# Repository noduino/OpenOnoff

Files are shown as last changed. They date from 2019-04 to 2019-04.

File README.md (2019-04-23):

Noduino Open Onoff
=======================================

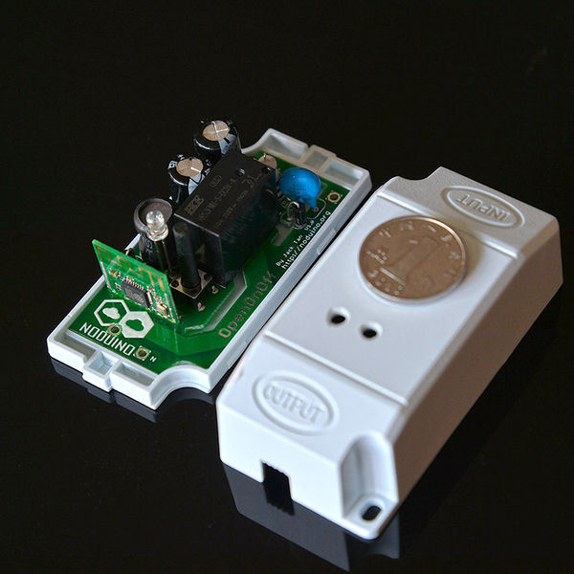
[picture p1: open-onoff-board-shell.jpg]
Noduino Open Onoff Shell


[*Noduino Open Onoff (OpenOnoff V1.0)*](http://wiki.jackslab.org/Noduino_OpenOnoff)

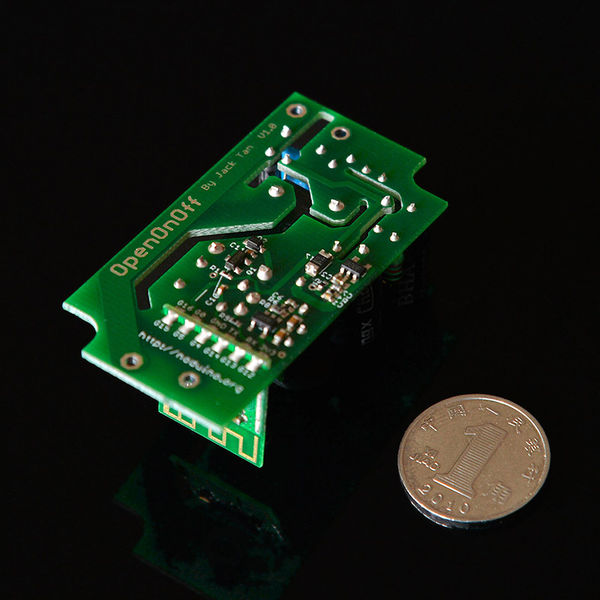
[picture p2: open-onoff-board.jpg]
Noduino Open Onoff Board


[*Noduino Open Onoff (OpenOnoff V1.0)*](http://wiki.jackslab.org/Noduino_OpenOnoff)

Overview
-------------------

* AC 85V - 250V WiFi Smart Switch
* ESP8285 inside
* 250V 10A relay
* Shell size 63mm x 33mm x 21mm (H)

Shell
-------------------

* https://item.taobao.com/item.htm?id=535597515580

WiFi Module
-------------------

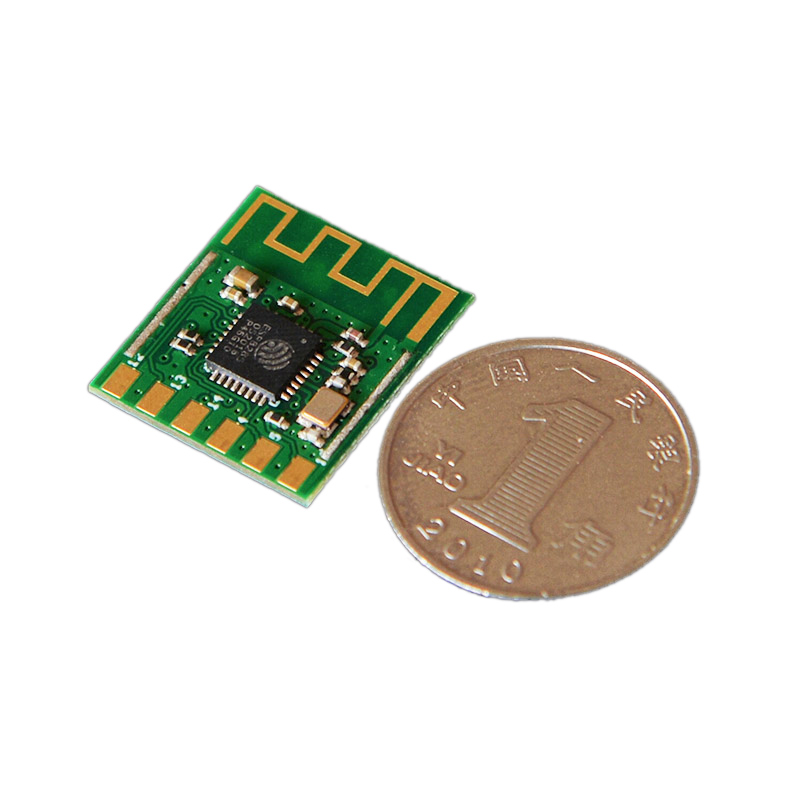
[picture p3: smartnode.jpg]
NodeC


[*Noduino NodeC WiFi Module*](http://wiki.jackslab.org/Noduino_SmartNode)

SCH
-------------------

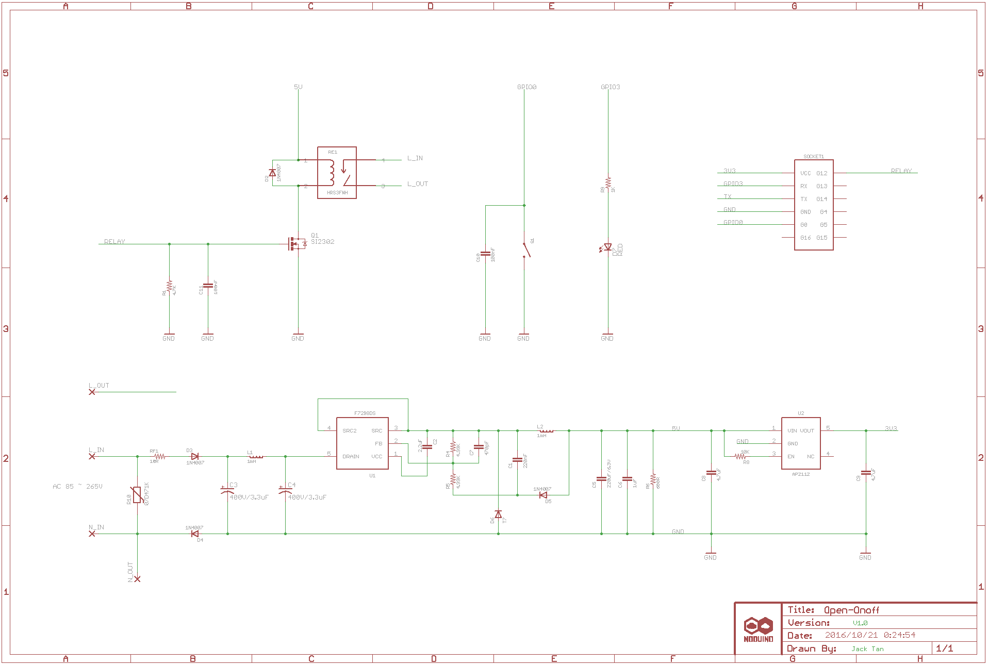
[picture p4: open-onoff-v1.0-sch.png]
Noduino Open Onoff sch


[*Noduino Open Onoff (OpenOnoff V1.0)*](http://wiki.jackslab.org/Noduino_OpenOnoff)

Layout
-------------------

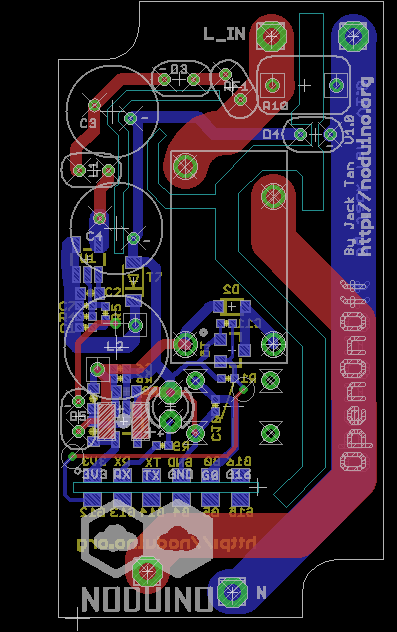
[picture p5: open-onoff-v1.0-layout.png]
Noduino Open Onoff layout


[*Noduino Open Onoff (OpenOnoff V1.0)*](http://wiki.jackslab.org/Noduino_OpenOnoff)

WiKi
-------------------

* http://wiki.jackslab.org/Noduino_OpenOnoff

License Information
-------------------
The hardware is released under [Creative Commons ShareAlike 4.0 International](https://creativecommons.org/licenses/by-sa/4.0/).

Distributed as-is; no warranty is given.

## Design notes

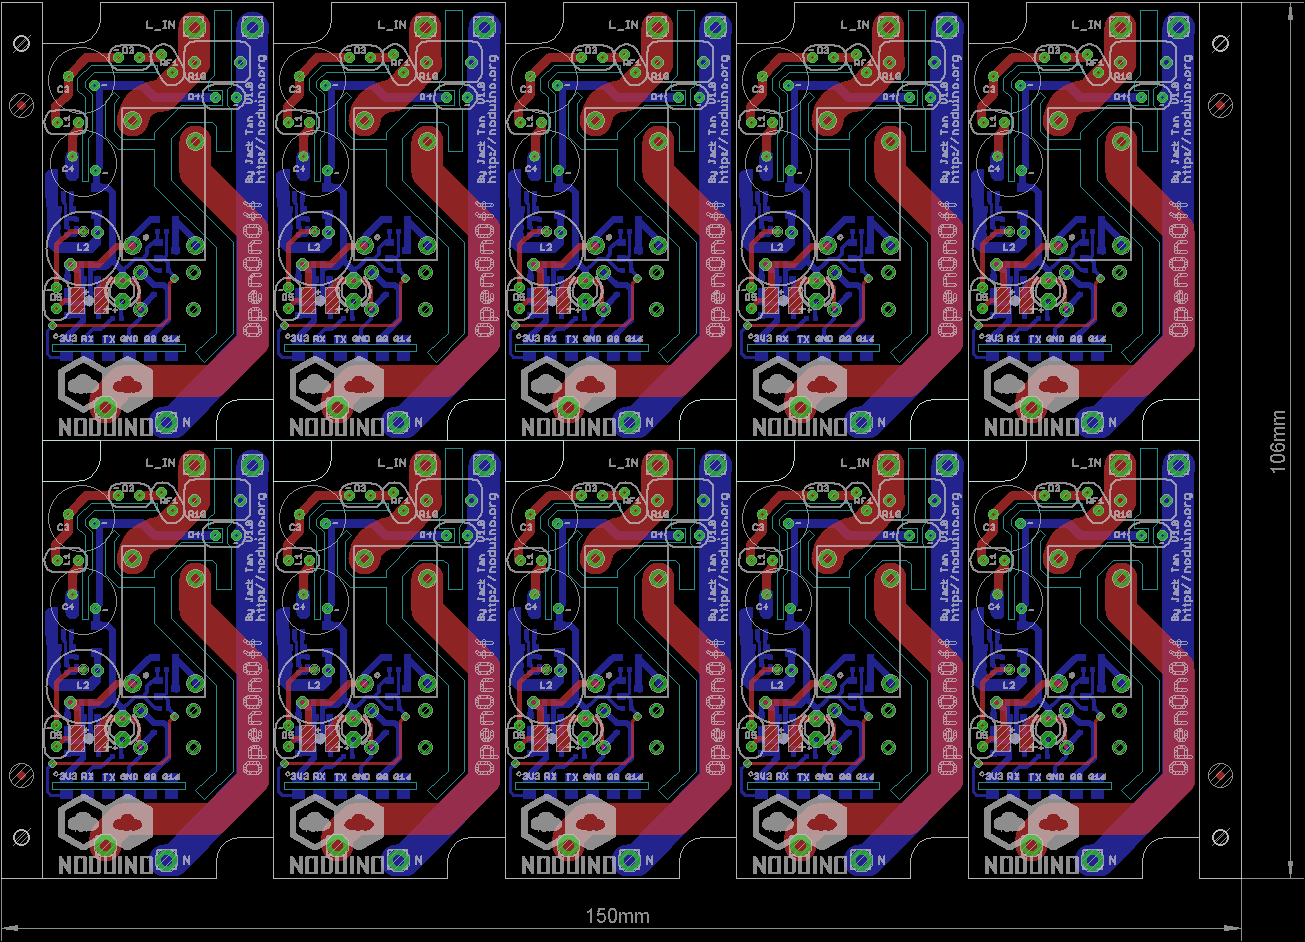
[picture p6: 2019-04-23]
V1.0/Noduino-Open-Onoff-V1.0-Produce-layout.png

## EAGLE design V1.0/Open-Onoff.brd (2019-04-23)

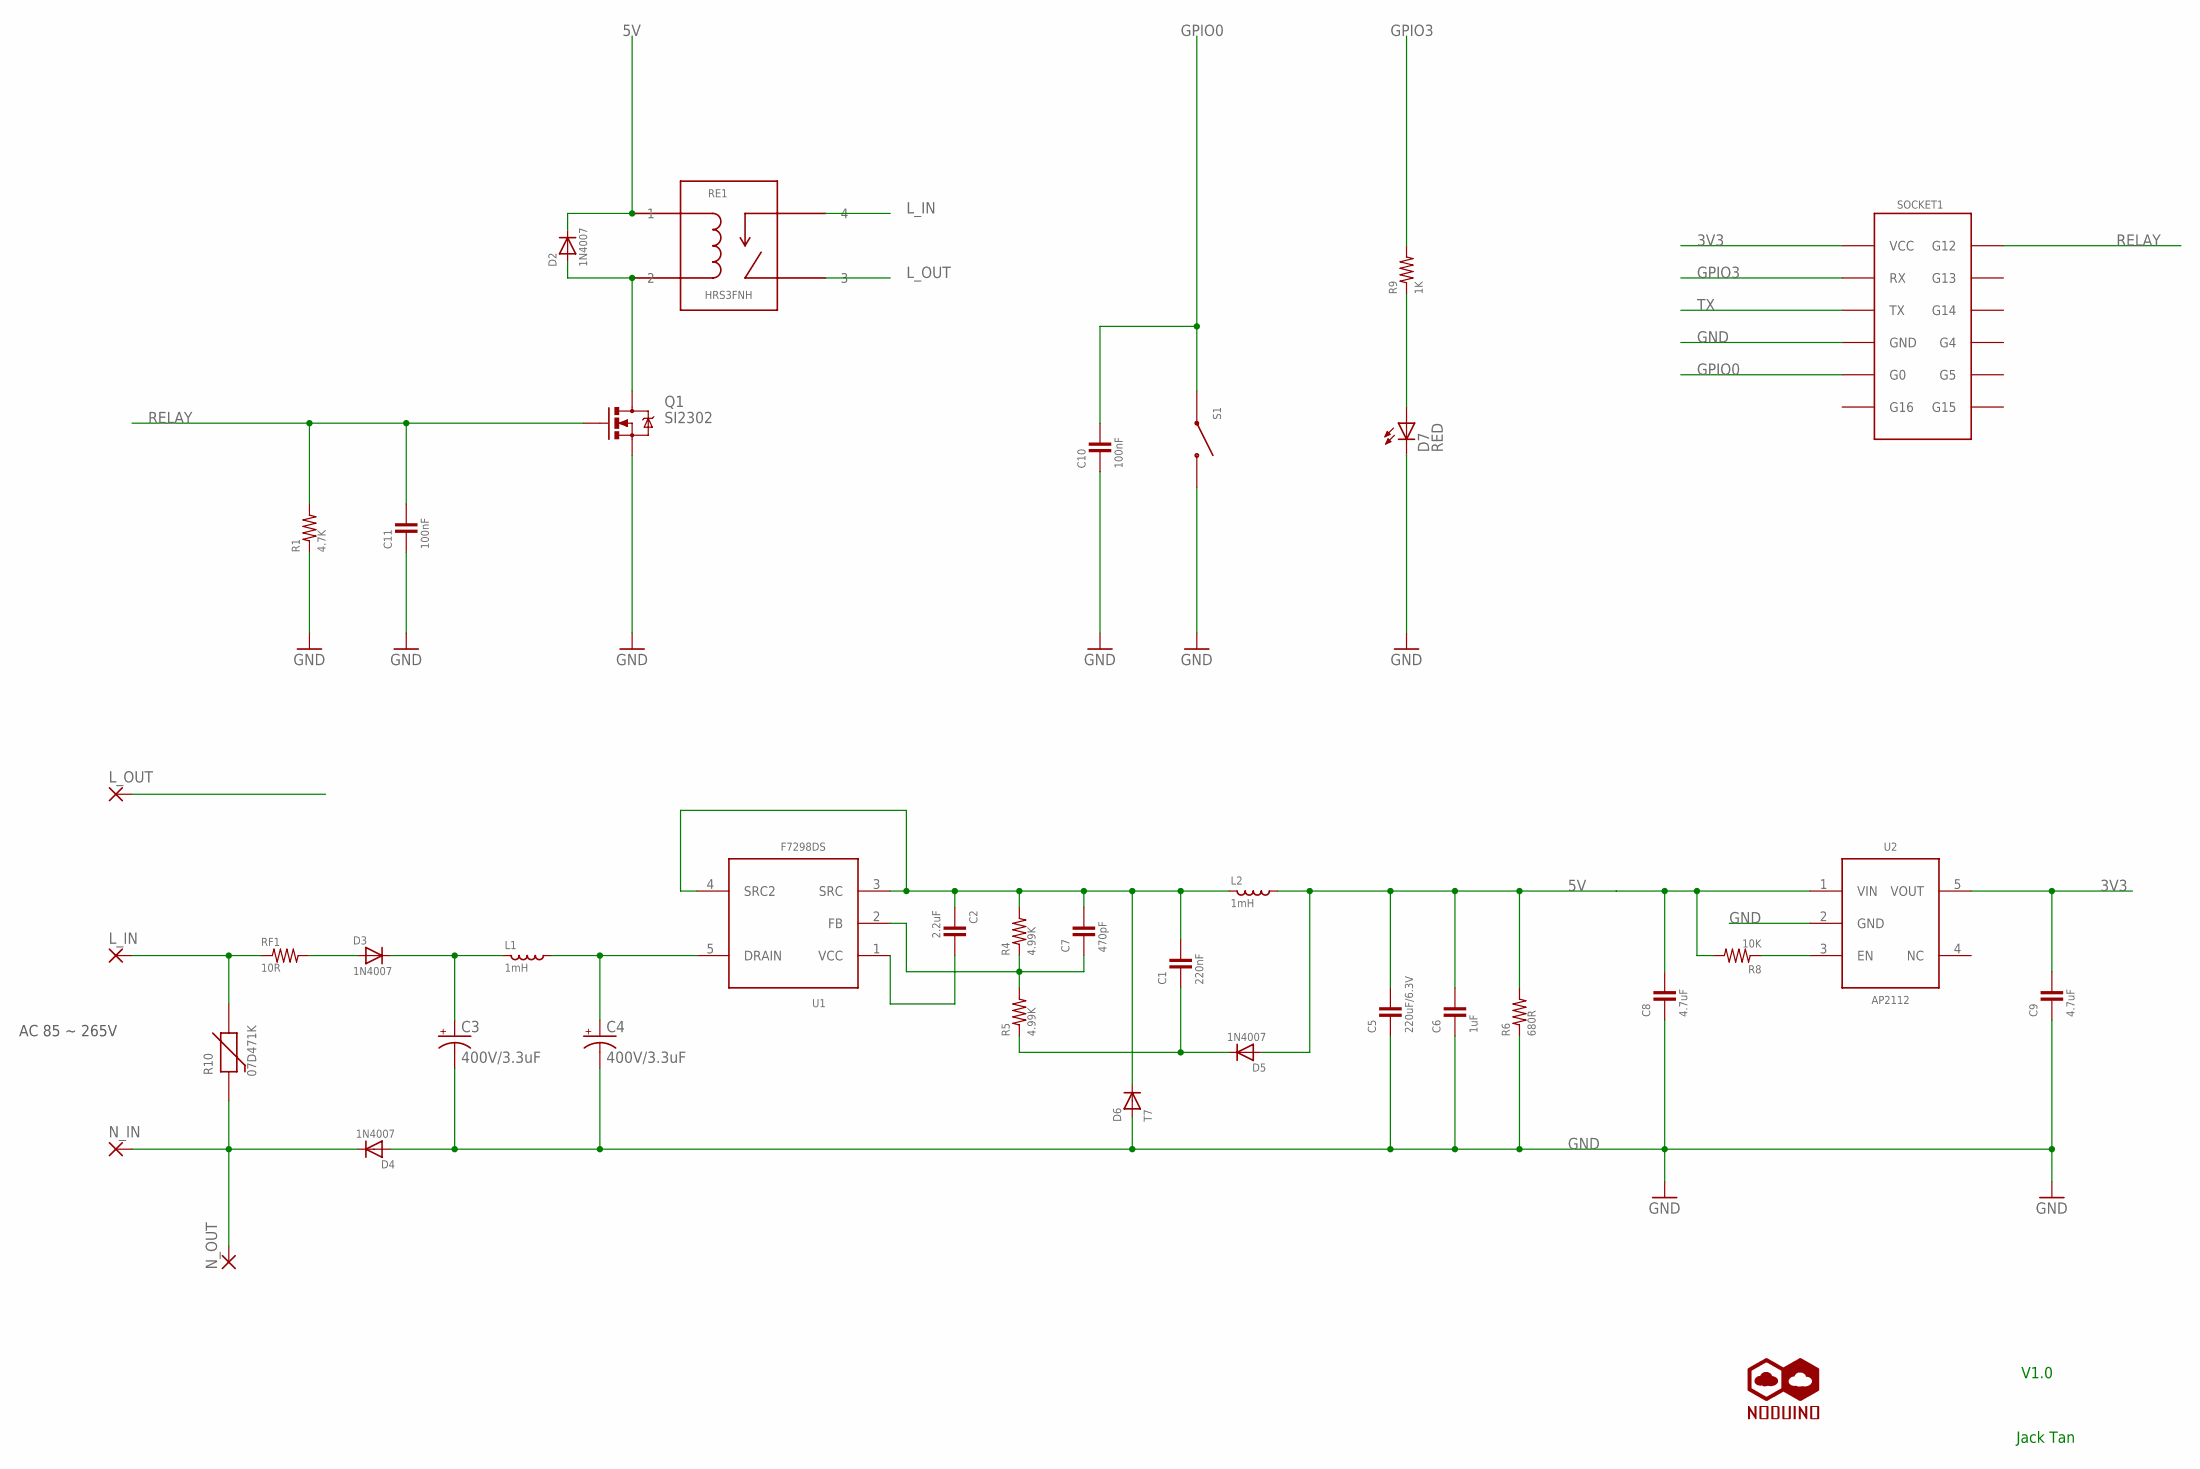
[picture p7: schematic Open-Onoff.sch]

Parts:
C1: 220nF; 0402-CAP
C2: 2.2uF; 0603-CAP
C3, C4: 400V/3.3uF; CPOL-RADIOA-3.3UF-400V
C5: 220uF/6.3V; B3528-CAP
C6: 1uF; 0402-CAP
C7: 470pF; 0402-CAP
C8, C9: 4.7uF; 0603-CAP
C10, C11: 100nF; 0402-CAP
D2: 1N4007; SOD-323
D3, D4, D5: 1N4007; 2.54-0.5
D6: T7; SOD-123
D7: RED; LED3MM
L1: 1mH; 2.54-0.5
L2: 1mH; INDUCTOR-5-0.5
L_IN: 2,15/1,0
L_OUT: 2,15/1,0
N_IN: 2,15/1,0
N_OUT: 2,15/1,0
Q1: SI2302; SOT23-3
R1: 4.7K; 0402-RES
R4, R5: 4.99K; 0402-RES
R6: 680R; 0402-RES
R8: 10K; 0603-RES
R9: 1K; 0402-RES
R10: 07D471K
RE1: HRS3FNH; HKE-HRS3FN
RF1: 10R; 2.54-0.5
S1: SWITCH-4DIPTS-037; SWITCH-TS-037
SOCKET1: MOD-SOCKET-V2.0; MOD-PLUG-SOCKET-V2.0
U1: F7298; SOT23-5
U2: AP2112; SOT23-5
U$1: NODUINO-LOGO-ALL; NODUINO-ALL-1

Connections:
3V3: C9.2, SOCKET1.1 (VCC), U2.5 (VOUT)
5V: C5.2, C6.2, C8.2, D2.1 (C), D5.P$1 (A), L2.P$2 (X2), R6.2, R8.2, RE1.1, U2.1 (VIN)
GND: C3.P$2 (-), C4.P$2 (-), C5.1, C6.1, C8.1, C9.1, C10.1, C11.1, D4.P$1 (A), D6.A, D7.K (C), Q1.2 (S), R1.1, R6.1, S1.P$1 (1), SOCKET1.4 (GND), U2.2 (GND)
GPIO0: C10.2, S1.P$3 (2), SOCKET1.5 (G0)
GPIO3: R9.2, SOCKET1.2 (RX)
L_IN: L_IN.1, R10.P$2 (2), RE1.4, RF1.P$1 (1)
L_OUT: L_OUT.1, RE1.3
N: D4.P$2 (C), N_IN.1, N_OUT.1, R10.P$1 (1)
unnamed: D2.2 (A), Q1.3 (D), RE1.2
unnamed: C3.P$1 (+), D3.P$2 (C), L1.P$1 (X1)
unnamed: C4.P$1 (+), L1.P$2 (X2), U1.5 (DRAIN)
unnamed: C1.2, C2.1, C7.2, D6.C, L2.P$1 (X1), R4.2, U1.3 (SRC), U1.4 (SRC2)
unnamed: D3.P$1 (A), RF1.P$2 (2)
unnamed: C2.2, U1.1 (VCC)
unnamed: C7.1, R4.1, R5.2, U1.2 (FB)
unnamed: C1.1, D5.P$2 (C), R5.1
unnamed: R8.1, U2.3 (EN)
unnamed: D7.A, R9.1
RELAY: C11.2, Q1.1 (G), R1.2, SOCKET1.12 (G12)
TX: SOCKET1.3 (TX)

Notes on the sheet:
Jack Tan
V1.0
AC 85 ~ 265V

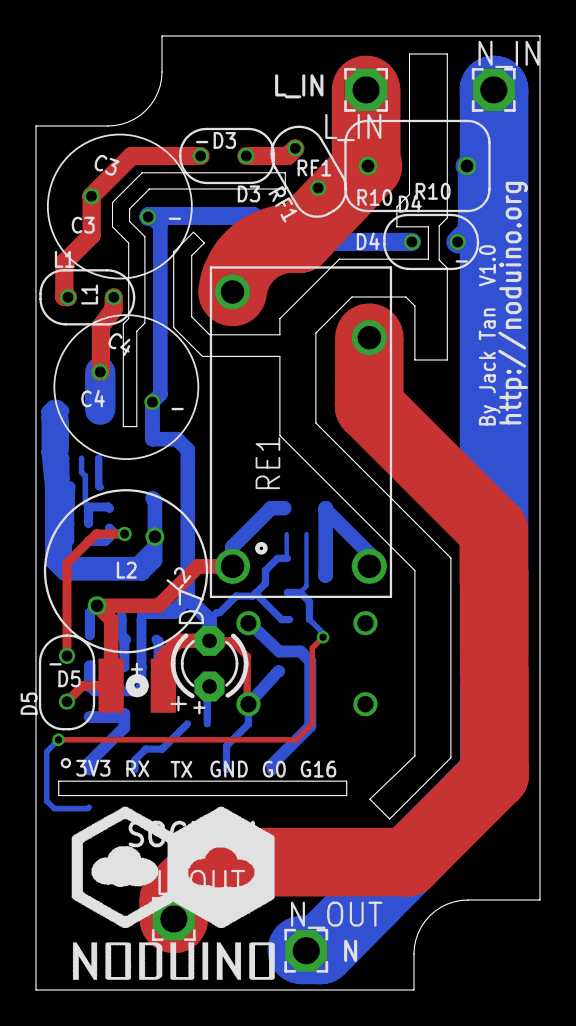
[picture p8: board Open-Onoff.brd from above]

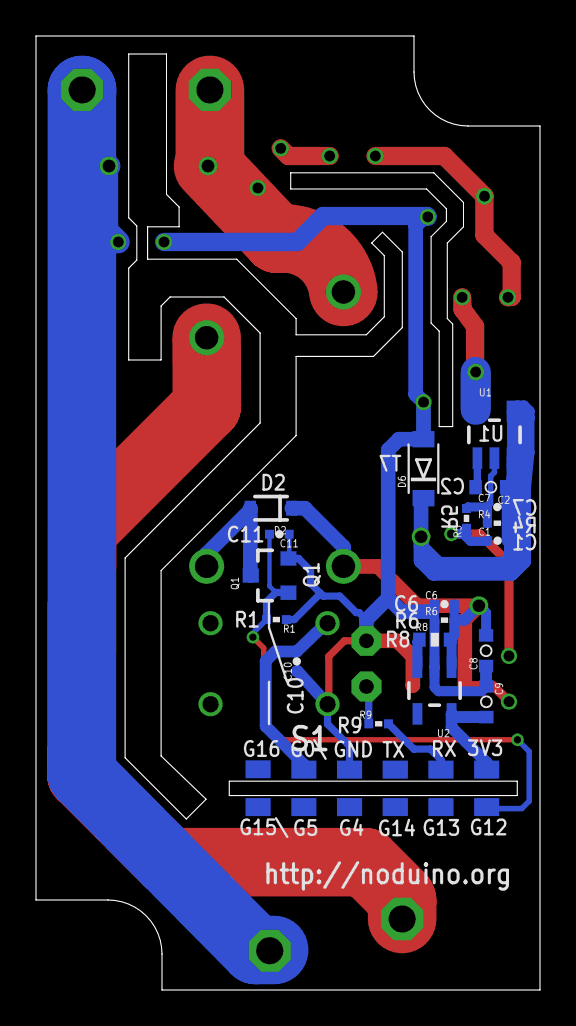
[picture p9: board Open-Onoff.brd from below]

Board: 2 copper layers, 28.0 x 53.0 mm, 38 parts (20 on the bottom side), 19 nets.

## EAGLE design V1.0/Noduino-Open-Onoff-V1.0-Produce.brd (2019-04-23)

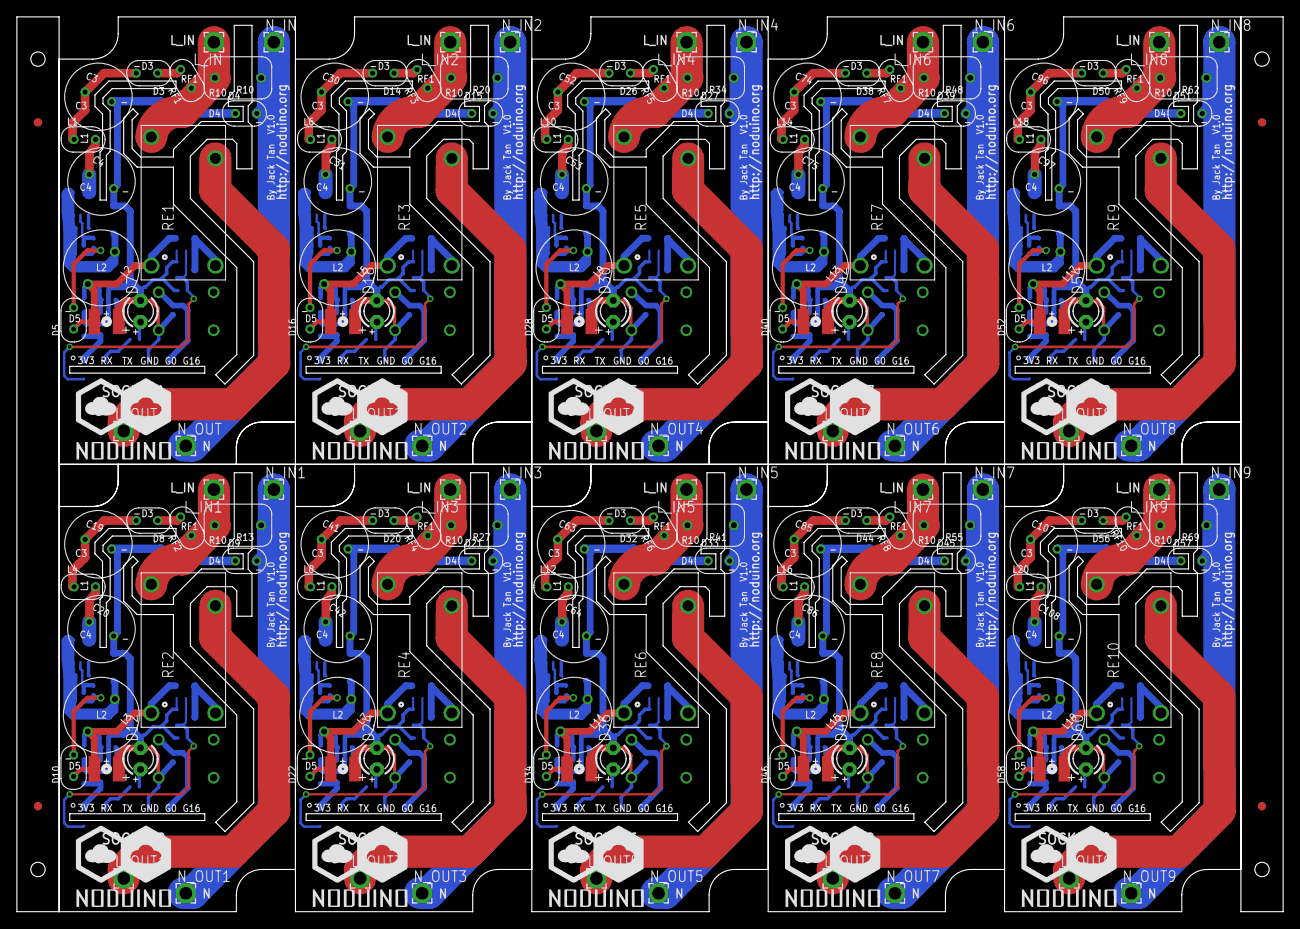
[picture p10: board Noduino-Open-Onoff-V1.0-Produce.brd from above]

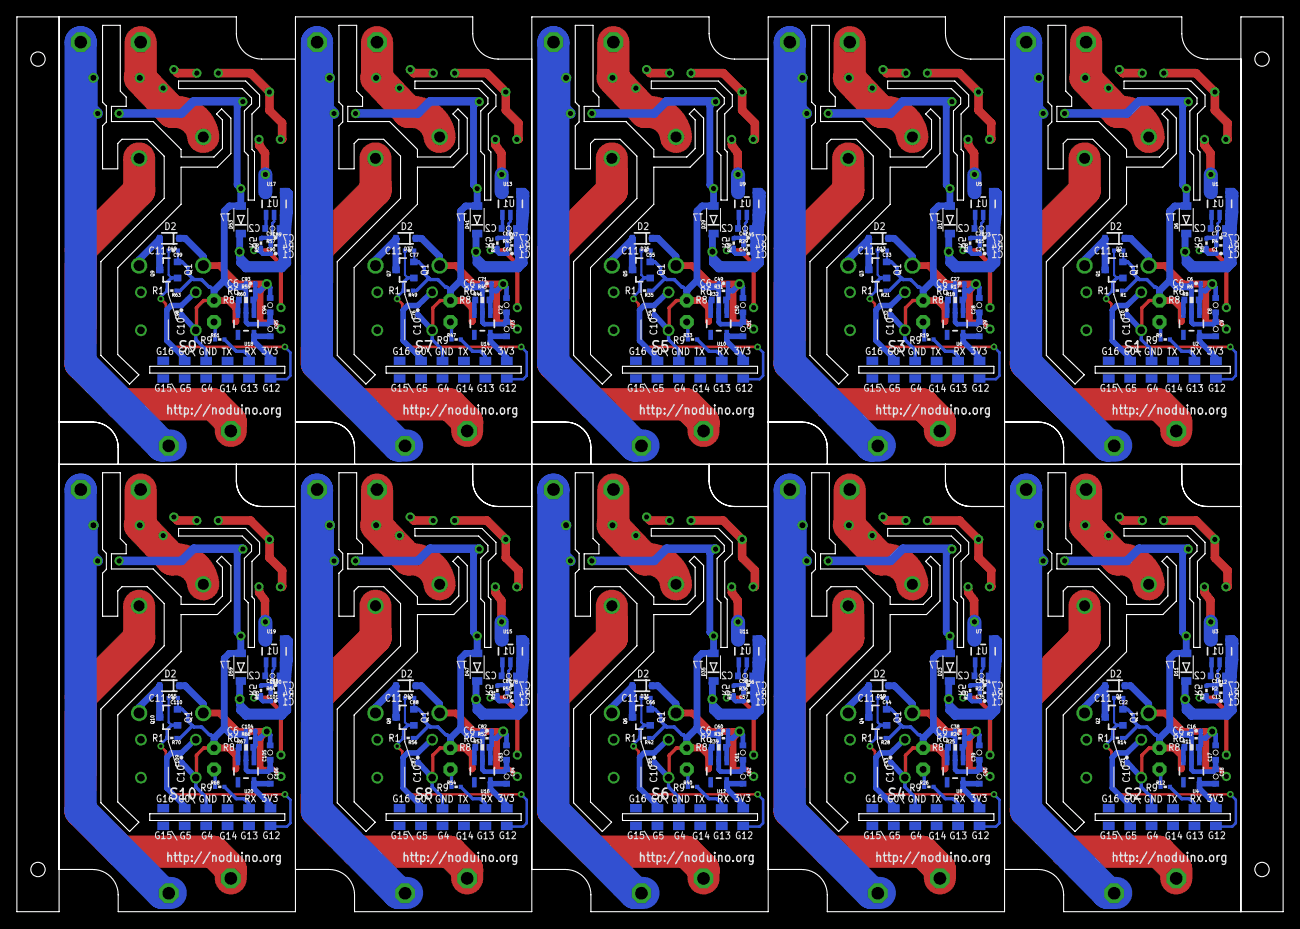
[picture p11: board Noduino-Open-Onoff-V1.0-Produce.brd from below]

Board: 2 copper layers, 150.0 x 106.0 mm, 384 parts (200 on the bottom side), 190 nets.

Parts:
C1, C13, C24, C35, C46, C57, C68, C79, C90, C101: 220nF; 0402-CAP
C2, C12, C23, C34, C45, C56, C67, C78, C89, C100: 2.2uF; 0603-CAP
C3, C4, C19, C20, C30, C31, C41, C42, C52, C53, C63, C64, C74, C75, C85, C86, C96, C97, C107, C108: 400V/3.3uF; CPOL-RADIOA-3.3UF-400V
C5, C15, C26, C37, C48, C59, C70, C81, C92, C103: 100uF/6.3V; B3528-CAP
C6, C16, C27, C38, C49, C60, C71, C82, C93, C104: 1uF; 0402-CAP
C7, C14, C25, C36, C47, C58, C69, C80, C91, C102: 470pF; 0402-CAP
C8, C9, C17, C18, C28, C29, C39, C40, C50, C51, C61, C62, C72, C73, C83, C84, C94, C95, C105, C106: 4.7uF; 0603-CAP
C10, C11, C21, C22, C32, C33, C43, C44, C54, C55, C65, C66, C76, C77, C87, C88, C98, C99, C109, C110: 100nF; 0402-CAP
D1, D2, D13, D19, D25, D31, D37, D43, D49, D55: 1N4007; SOD-323
D3, D4, D5, D8, D9, D10, D14, D15, D16, D20, D21, D22, D26, D27, D28, D32, D33, D34, D38, D39, D40, D44, D45, D46, D50, D51, D52, D56, D57, D58: 1N4007; 2.54-0.5
D6, D11, D17, D23, D29, D35, D41, D47, D53, D59: T7; SOD-123
D7, D12, D18, D24, D30, D36, D42, D48, D54, D60: RED; LED3MM
E$1, E$2, E$3, E$4: MARK-1MM
L1, L4, L6, L8, L10, L12, L14, L16, L18, L20: 1mH; 2.54-0.5
L2, L3, L5, L7, L9, L11, L13, L15, L17, L19: 1mH; INDUCTOR-5-0.5
L_IN, L_IN1, L_IN2, L_IN3, L_IN4, L_IN5, L_IN6, L_IN7, L_IN8, L_IN9: 2,15/1,0
L_OUT, L_OUT1, L_OUT2, L_OUT3, L_OUT4, L_OUT5, L_OUT6, L_OUT7, L_OUT8, L_OUT9: 2,15/1,0
N_IN, N_IN1, N_IN2, N_IN3, N_IN4, N_IN5, N_IN6, N_IN7, N_IN8, N_IN9: 2,15/1,0
N_OUT, N_OUT1, N_OUT2, N_OUT3, N_OUT4, N_OUT5, N_OUT6, N_OUT7, N_OUT8, N_OUT9: 2,15/1,0
Q1, Q2, Q3, Q4, Q5, Q6, Q7, Q8, Q9, Q10: SI2302; SOT23-3
R1, R9, R12, R14, R19, R21, R26, R28, R33, R35, R40, R42, R47, R49, R54, R56, R61, R63, R68, R70: 1K; 0402-RES
R2, R3, R4, R5, R15, R16, R22, R23, R29, R30, R36, R37, R43, R44, R50, R51, R57, R58, R64, R65: 4.99K; 0402-RES
R6, R7, R17, R24, R31, R38, R45, R52, R59, R66: 680R; 0402-RES
R8, R11, R18, R25, R32, R39, R46, R53, R60, R67: 10K; 0603-RES
R10, R13, R20, R27, R34, R41, R48, R55, R62, R69: 07D471K
RE1, RE2, RE3, RE4, RE5, RE6, RE7, RE8, RE9, RE10: HRS3FNH; HKE-HRS3FN
RF1, RF2, RF3, RF4, RF5, RF6, RF7, RF8, RF9, RF10: 10R; 2.54-0.5
S1, S2, S3, S4, S5, S6, S7, S8, S9, S10: SWITCH-TS-037
SOCKET1, SOCKET2, SOCKET3, SOCKET4, SOCKET5, SOCKET6, SOCKET7, SOCKET8, SOCKET9, SOCKET10: MOD-SOCKET-V2.0; MOD-PLUG-SOCKET-V2.0
U1, U3, U5, U7, U9, U11, U13, U15, U17, U19: F7298; SOT23-5
U2, U4, U6, U8, U10, U12, U14, U16, U18, U20: AP2112; SOT23-5
U$1, U$2, U$3, U$4, U$5, U$6, U$7, U$8, U$9, U$10: NODUINO-LOGO-ALL; NODUINO-ALL-1

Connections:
3V1: C18.2, SOCKET2.1, U4.5
3V2: C29.2, SOCKET3.1, U6.5
3V3: C9.2, SOCKET1.1, U2.5
3V4: C40.2, SOCKET4.1, U8.5
3V5: C51.2, SOCKET5.1, U10.5
3V6: C62.2, SOCKET6.1, U12.5
3V7: C73.2, SOCKET7.1, U14.5
3V8: C84.2, SOCKET8.1, U16.5
3V9: C95.2, SOCKET9.1, U18.5
3V10: C106.2, SOCKET10.1, U20.5
5V: C5.2, C6.2, C8.2, D2.1, D5.P$1, L2.P$2, R6.2, R8.2, RE1.1, U2.1
5V1: C15.2, C16.2, C17.2, D1.1, D10.P$1, L3.P$2, R7.2, R11.2, RE2.1, U4.1
5V2: C26.2, C27.2, C28.2, D13.1, D16.P$1, L5.P$2, R17.2, R18.2, RE3.1, U6.1
5V3: C37.2, C38.2, C39.2, D19.1, D22.P$1, L7.P$2, R24.2, R25.2, RE4.1, U8.1
5V4: C48.2, C49.2, C50.2, D25.1, D28.P$1, L9.P$2, R31.2, R32.2, RE5.1, U10.1
5V5: C59.2, C60.2, C61.2, D31.1, D34.P$1, L11.P$2, R38.2, R39.2, RE6.1, U12.1
5V6: C70.2, C71.2, C72.2, D37.1, D40.P$1, L13.P$2, R45.2, R46.2, RE7.1, U14.1
5V7: C81.2, C82.2, C83.2, D43.1, D46.P$1, L15.P$2, R52.2, R53.2, RE8.1, U16.1
5V8: C92.2, C93.2, C94.2, D49.1, D52.P$1, L17.P$2, R59.2, R60.2, RE9.1, U18.1
5V9: C103.2, C104.2, C105.2, D55.1, D58.P$1, L19.P$2, R66.2, R67.2, RE10.1, U20.1
GND: C3.P$2, C4.P$2, C5.1, C6.1, C8.1, C9.1, C10.1, C11.1, D4.P$1, D6.A, D7.K, Q1.2, R1.1, R6.1, S1.P$1, SOCKET1.4, U2.2
GND1: C15.1, C16.1, C17.1, C18.1, C19.P$2, C20.P$2, C21.1, C22.1, D9.P$1, D11.A, D12.K, Q2.2, R7.1, R14.1, S2.P$1, SOCKET2.4, U4.2
GND2: C26.1, C27.1, C28.1, C29.1, C30.P$2, C31.P$2, C32.1, C33.1, D15.P$1, D17.A, D18.K, Q3.2, R17.1, R21.1, S3.P$1, SOCKET3.4, U6.2
GND3: C37.1, C38.1, C39.1, C40.1, C41.P$2, C42.P$2, C43.1, C44.1, D21.P$1, D23.A, D24.K, Q4.2, R24.1, R28.1, S4.P$1, SOCKET4.4, U8.2
GND4: C48.1, C49.1, C50.1, C51.1, C52.P$2, C53.P$2, C54.1, C55.1, D27.P$1, D29.A, D30.K, Q5.2, R31.1, R35.1, S5.P$1, SOCKET5.4, U10.2
GND5: C59.1, C60.1, C61.1, C62.1, C63.P$2, C64.P$2, C65.1, C66.1, D33.P$1, D35.A, D36.K, Q6.2, R38.1, R42.1, S6.P$1, SOCKET6.4, U12.2
GND6: C70.1, C71.1, C72.1, C73.1, C74.P$2, C75.P$2, C76.1, C77.1, D39.P$1, D41.A, D42.K, Q7.2, R45.1, R49.1, S7.P$1, SOCKET7.4, U14.2
GND7: C81.1, C82.1, C83.1, C84.1, C85.P$2, C86.P$2, C87.1, C88.1, D45.P$1, D47.A, D48.K, Q8.2, R52.1, R56.1, S8.P$1, SOCKET8.4, U16.2
GND8: C92.1, C93.1, C94.1, C95.1, C96.P$2, C97.P$2, C98.1, C99.1, D51.P$1, D53.A, D54.K, Q9.2, R59.1, R63.1, S9.P$1, SOCKET9.4, U18.2
GND9: C103.1, C104.1, C105.1, C106.1, C107.P$2, C108.P$2, C109.1, C110.1, D57.P$1, D59.A, D60.K, Q10.2, R66.1, R70.1, S10.P$1, SOCKET10.4, U20.2
GPIO0: C10.2, S1.P$3, SOCKET1.5
GPIO1: R12.2, SOCKET2.2
GPIO2: C21.2, S2.P$3, SOCKET2.5
GPIO3: R9.2, SOCKET1.2
GPIO4: R19.2, SOCKET3.2
GPIO5: C32.2, S3.P$3, SOCKET3.5
GPIO6: R26.2, SOCKET4.2
GPIO7: C43.2, S4.P$3, SOCKET4.5
GPIO8: R33.2, SOCKET5.2
GPIO9: C54.2, S5.P$3, SOCKET5.5
GPIO10: R40.2, SOCKET6.2
GPIO11: C65.2, S6.P$3, SOCKET6.5
GPIO12: R47.2, SOCKET7.2
GPIO13: C76.2, S7.P$3, SOCKET7.5
GPIO14: R54.2, SOCKET8.2
GPIO15: C87.2, S8.P$3, SOCKET8.5
GPIO16: R61.2, SOCKET9.2
GPIO17: C98.2, S9.P$3, SOCKET9.5
GPIO18: R68.2, SOCKET10.2
GPIO19: C109.2, S10.P$3, SOCKET10.5
L_IN: L_IN.1, R10.P$2, RE1.4, RF1.P$1
L_IN1: L_IN1.1, R13.P$2, RE2.4, RF2.P$1
L_IN2: L_IN2.1, R20.P$2, RE3.4, RF3.P$1
L_IN3: L_IN3.1, R27.P$2, RE4.4, RF4.P$1
L_IN4: L_IN4.1, R34.P$2, RE5.4, RF5.P$1
L_IN5: L_IN5.1, R41.P$2, RE6.4, RF6.P$1
L_IN6: L_IN6.1, R48.P$2, RE7.4, RF7.P$1
L_IN7: L_IN7.1, R55.P$2, RE8.4, RF8.P$1
L_IN8: L_IN8.1, R62.P$2, RE9.4, RF9.P$1
L_IN9: L_IN9.1, R69.P$2, RE10.4, RF10.P$1
L_OUT: L_OUT.1, RE1.3
L_OUT1: L_OUT1.1, RE2.3
L_OUT2: L_OUT2.1, RE3.3
L_OUT3: L_OUT3.1, RE4.3
L_OUT4: L_OUT4.1, RE5.3
L_OUT5: L_OUT5.1, RE6.3
L_OUT6: L_OUT6.1, RE7.3
L_OUT7: L_OUT7.1, RE8.3
L_OUT8: L_OUT8.1, RE9.3
L_OUT9: L_OUT9.1, RE10.3
N: D4.P$2, N_IN.1, N_OUT.1, R10.P$1
N1: D9.P$2, N_IN1.1, N_OUT1.1, R13.P$1
N2: D15.P$2, N_IN2.1, N_OUT2.1, R20.P$1
N3: D21.P$2, N_IN3.1, N_OUT3.1, R27.P$1
N4: D27.P$2, N_IN4.1, N_OUT4.1, R34.P$1
N5: D33.P$2, N_IN5.1, N_OUT5.1, R41.P$1
N6: D39.P$2, N_IN6.1, N_OUT6.1, R48.P$1
N7: D45.P$2, N_IN7.1, N_OUT7.1, R55.P$1
N8: D51.P$2, N_IN8.1, N_OUT8.1, R62.P$1
N9: D57.P$2, N_IN9.1, N_OUT9.1, R69.P$1
unnamed: D1.2, Q2.3, RE2.2
unnamed: D2.2, Q1.3, RE1.2
unnamed: C3.P$1, D3.P$2, L1.P$1
unnamed: C19.P$1, D8.P$2, L4.P$1
unnamed: C4.P$1, L1.P$2, U1.5
unnamed: C1.2, C2.1, C7.2, D6.C, L2.P$1, R4.2, U1.3, U1.4
unnamed: D3.P$1, RF1.P$2
unnamed: C20.P$1, L4.P$2, U3.5
unnamed: C12.1, C13.2, C14.2, D11.C, L3.P$1, R2.2, U3.3, U3.4
unnamed: C2.2, U1.1
unnamed: C7.1, R4.1, R5.2, U1.2
unnamed: C1.1, D5.P$2, R5.1
unnamed: R8.1, U2.3
unnamed: D7.A, R9.1
unnamed: D8.P$1, RF2.P$2
unnamed: C12.2, U3.1
unnamed: C14.1, R2.1, R3.2, U3.2
unnamed: C13.1, D10.P$2, R3.1
unnamed: R11.1, U4.3
unnamed: D12.A, R12.1
unnamed: D13.2, Q3.3, RE3.2
unnamed: C30.P$1, D14.P$2, L6.P$1
unnamed: C31.P$1, L6.P$2, U5.5
unnamed: C23.1, C24.2, C25.2, D17.C, L5.P$1, R15.2, U5.3, U5.4
unnamed: D14.P$1, RF3.P$2
unnamed: C23.2, U5.1
unnamed: C25.1, R15.1, R16.2, U5.2
unnamed: C24.1, D16.P$2, R16.1
unnamed: R18.1, U6.3
unnamed: D18.A, R19.1
unnamed: D19.2, Q4.3, RE4.2
unnamed: C41.P$1, D20.P$2, L8.P$1
unnamed: C42.P$1, L8.P$2, U7.5
unnamed: C34.1, C35.2, C36.2, D23.C, L7.P$1, R22.2, U7.3, U7.4
unnamed: D20.P$1, RF4.P$2
unnamed: C34.2, U7.1
unnamed: C36.1, R22.1, R23.2, U7.2
unnamed: C35.1, D22.P$2, R23.1
unnamed: R25.1, U8.3
unnamed: D24.A, R26.1
unnamed: D25.2, Q5.3, RE5.2
unnamed: C52.P$1, D26.P$2, L10.P$1
unnamed: C53.P$1, L10.P$2, U9.5
unnamed: C45.1, C46.2, C47.2, D29.C, L9.P$1, R29.2, U9.3, U9.4
unnamed: D26.P$1, RF5.P$2
unnamed: C45.2, U9.1
unnamed: C47.1, R29.1, R30.2, U9.2
unnamed: C46.1, D28.P$2, R30.1
unnamed: R32.1, U10.3
unnamed: D30.A, R33.1
unnamed: D31.2, Q6.3, RE6.2
unnamed: C63.P$1, D32.P$2, L12.P$1
unnamed: C64.P$1, L12.P$2, U11.5
unnamed: C56.1, C57.2, C58.2, D35.C, L11.P$1, R36.2, U11.3, U11.4
unnamed: D32.P$1, RF6.P$2
unnamed: C56.2, U11.1
unnamed: C58.1, R36.1, R37.2, U11.2
unnamed: C57.1, D34.P$2, R37.1
unnamed: R39.1, U12.3
unnamed: D36.A, R40.1
unnamed: D37.2, Q7.3, RE7.2
unnamed: C74.P$1, D38.P$2, L14.P$1
unnamed: C75.P$1, L14.P$2, U13.5
unnamed: C67.1, C68.2, C69.2, D41.C, L13.P$1, R43.2, U13.3, U13.4
unnamed: D38.P$1, RF7.P$2
unnamed: C67.2, U13.1
unnamed: C69.1, R43.1, R44.2, U13.2
unnamed: C68.1, D40.P$2, R44.1
unnamed: R46.1, U14.3
unnamed: D42.A, R47.1
unnamed: D43.2, Q8.3, RE8.2
unnamed: C85.P$1, D44.P$2, L16.P$1
unnamed: C86.P$1, L16.P$2, U15.5
unnamed: C78.1, C79.2, C80.2, D47.C, L15.P$1, R50.2, U15.3, U15.4
unnamed: D44.P$1, RF8.P$2
unnamed: C78.2, U15.1
unnamed: C80.1, R50.1, R51.2, U15.2
unnamed: C79.1, D46.P$2, R51.1
unnamed: R53.1, U16.3
unnamed: D48.A, R54.1
unnamed: D49.2, Q9.3, RE9.2
unnamed: C96.P$1, D50.P$2, L18.P$1
unnamed: C97.P$1, L18.P$2, U17.5
unnamed: C89.1, C90.2, C91.2, D53.C, L17.P$1, R57.2, U17.3, U17.4
unnamed: D50.P$1, RF9.P$2
unnamed: C89.2, U17.1
unnamed: C91.1, R57.1, R58.2, U17.2
unnamed: C90.1, D52.P$2, R58.1
unnamed: R60.1, U18.3
unnamed: D54.A, R61.1
unnamed: D55.2, Q10.3, RE10.2
unnamed: C107.P$1, D56.P$2, L20.P$1
unnamed: C108.P$1, L20.P$2, U19.5
unnamed: C100.1, C101.2, C102.2, D59.C, L19.P$1, R64.2, U19.3, U19.4
unnamed: D56.P$1, RF10.P$2
unnamed: C100.2, U19.1
unnamed: C102.1, R64.1, R65.2, U19.2
unnamed: C101.1, D58.P$2, R65.1
unnamed: R67.1, U20.3
unnamed: D60.A, R68.1
RELAY: C11.2, Q1.1, R1.2, SOCKET1.12
RELAY1: C22.2, Q2.1, R14.2, SOCKET2.12
RELAY2: C33.2, Q3.1, R21.2, SOCKET3.12
RELAY3: C44.2, Q4.1, R28.2, SOCKET4.12
RELAY4: C55.2, Q5.1, R35.2, SOCKET5.12
RELAY5: C66.2, Q6.1, R42.2, SOCKET6.12
RELAY6: C77.2, Q7.1, R49.2, SOCKET7.12
RELAY7: C88.2, Q8.1, R56.2, SOCKET8.12
RELAY8: C99.2, Q9.1, R63.2, SOCKET9.12
RELAY9: C110.2, Q10.1, R70.2, SOCKET10.12
